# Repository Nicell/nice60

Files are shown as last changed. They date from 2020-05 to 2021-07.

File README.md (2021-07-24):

# This is the old DIY version of the nice!60. This is superseded by a new version, which is fully assembled and much more polished.
# Read more about this new version, and find where to purchase it at https://nicekeyboards.com/nice-60.
## nice60

The nice60 is a hotswap 60% board compatible with Pro Micro footprint boards. This includes the nice!nano, which supports bluetooth.

### BOM
Most parts come from LCSC.

|Qty |Reference(s) |Value |LCSC#/Location |
|----|---|---|---|
|61  |D1-D61 |1N4148 |C108804 |
|8 |D62-D69 |WS2812B |C114586 |
|1 |D70 |SK6812 Mini-E |Buy from Aliexpress|
|1 |J1 |USB C |C165948 |
|1 |J3 |JST-PH (battery) |C173752 |
|61  |MX1-MX61 |Hotswap Sockets |Buy from KBDFans |
|2 |R2, R3 |5.1k |C304897 |
|1 |SW1 |Reset Switch |C388295 |
|1 |U2 |USB ESD Protection |C7519 |
|1 |Stabilizers |4x2u 1x6.25u |Buy from KBDFans |
|6/12|N/A |M2x7mm Standoffs |Buy from Aliexpress|
|1 |USB Cable |Match Pro Micro USB|Anywhere |

### PCB

There are three gerber zips for PCBs.

1. pcb_gerbers.zip - The actual PCB gerbers
2. plate_gerbers.zip - The top plate for the board
3. backplate_gerbers.zip - The bottom case/plate for the board

These can be bought from JLCPCB the cheapest.

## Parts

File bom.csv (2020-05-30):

Item | Qty | Reference(s) | Value | LibPart | Footprint | Datasheet | LCSC
1 | 61 | D1, D2, D3, D4, D5, D6, D7, D8, D9, D10, D11, D12, D13, D14, D15, D16, D17, D18, D19, D20, D21, D22, D23, D24, D25, D26, D27, D28, D29, D30, D31, D32, D33, D34, D35, D36, D37, D38, D39, D40, D41, D42, D43, D44, D45, D46, D47, D48, D49, D50, D51, D52, D53, D54, D55, D56, D57, D58, D59, D60, D61 | D_Small | Device:D_Small | Diode_SMD:D_SOD-123 | ~ | C108804
2 | 8 | D62, D63, D64, D65, D66, D67, D68, D69 | WS2812B | LED:WS2812B | LED_SMD:LED_WS2812B_PLCC4_5.0x5.0mm_P3.2mm | https://cdn-shop.adafruit.com/datasheets/WS2812B.pdf | C114586
3 | 1 | D70 | SK6812 Mini-E | LED:WS2812B | nice60:SK6812Mini-E | https://cdn-shop.adafruit.com/datasheets/WS2812B.pdf | Buy from Aliexpress
5 | 1 | J1 | USB_C_Receptacle_USB2.0 | Connector:USB_C_Receptacle_USB2.0 | Type-C:HRO-TYPE-C-31-M-12-HandSoldering | https://www.usb.org/sites/default/files/documents/usb_type-c.zip | C165948
7 | 1 | J3 | Conn_01x02_Female | Connector:Conn_01x02_Female | Connector_JST:JST_PH_S2B-PH-K_1x02_P2.00mm_Horizontal | ~ | C173752
8 | 61 | MX1, MX2, MX3, MX4, MX5, MX6, MX7, MX8, MX9, MX10, MX11, MX12, MX13, MX14, MX15, MX16, MX17, MX18, MX19, MX20, MX21, MX22, MX23, MX24, MX25, MX26, MX27, MX28, MX29, MX30, MX31, MX32, MX33, MX34, MX35, MX36, MX37, MX38, MX39, MX40, MX41, MX42, MX43, MX44, MX45, MX46, MX47, MX48, MX49, MX50, MX51, MX52, MX53, MX54, MX55, MX56, MX57, MX58, MX59, MX60, MX61 | MX-LED | MX_Alps_Hybrid:MX-NoLED | MX_Only:MXOnly-1U-Hotswap |  | Buy from KBDFans
16 | 2 | R2, R3 | 5.1k | Device:R_Small | Resistor_SMD:R_1206_3216Metric_Pad1.42x1.75mm_HandSolder | ~ | C304897
17 | 1 | SW1 | SW_Push | Switch:SW_Push | Button_Switch_SMD:SW_SPST_TL3342 | ~ | C388295
19 | 1 | U2 | USBLC6-2SC6 | Power_Protection:USBLC6-2SC6 | Package_TO_SOT_SMD:SOT-23-6 | http://www2.st.com/resource/en/datasheet/CD00050750.pdf | C7519

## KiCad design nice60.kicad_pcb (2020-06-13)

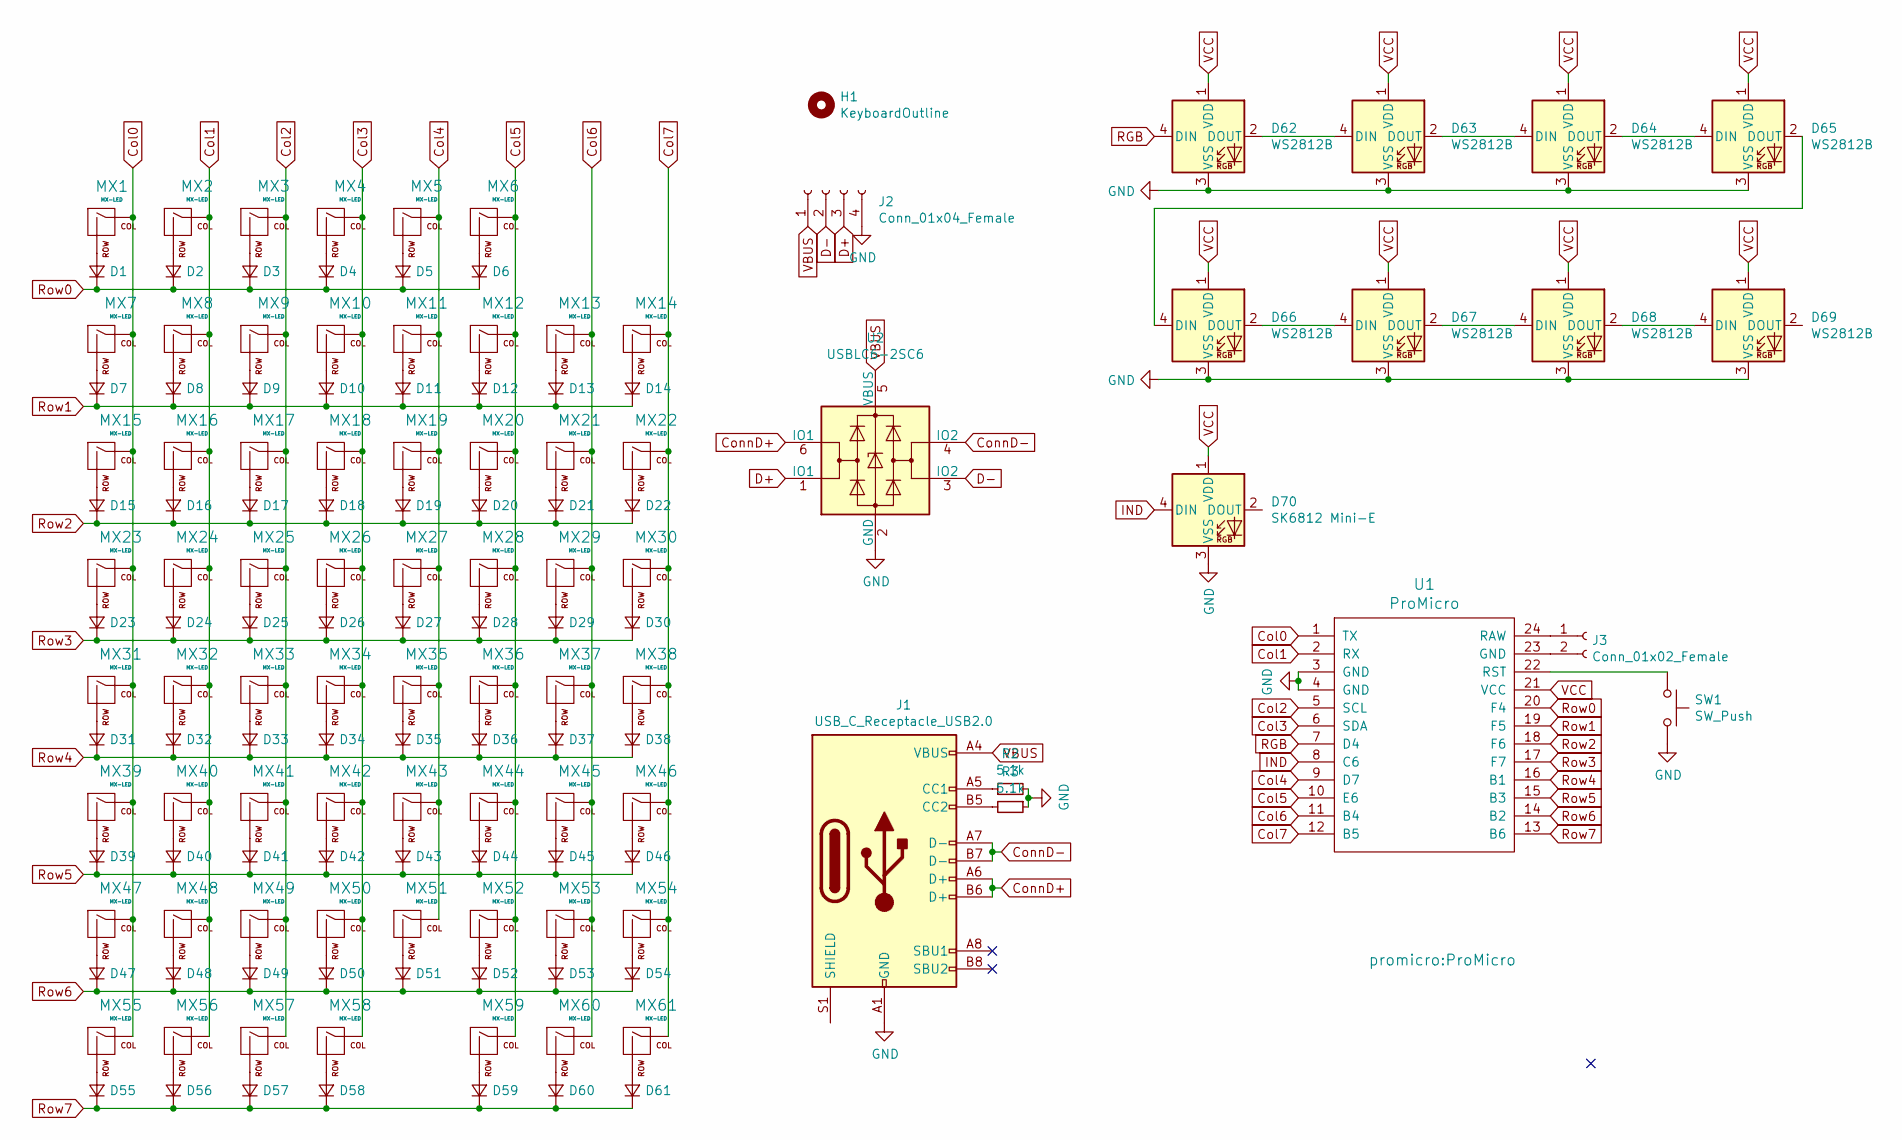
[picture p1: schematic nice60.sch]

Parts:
D1, D2, D3, D4, D5, D6, D7, D8, D9, D10, D11, D12, D13, D14, D15, D16, D17, D18, D19, D20, D21, D22, D23, D24, D25, D26, D27, D28, D29, D30, D31, D32, D33, D34, D35, D36, D37, D38, D39, D40, D41, D42, D43, D44, D45, D46, D47, D48, D49, D50, D51, D52, D53, D54, D55, D56, D57, D58, D59, D60, D61: D_Small; D_SOD-123; LCSC C108804
D62, D63, D64, D65, D66, D67, D68, D69: WS2812B; LED_WS2812B_PLCC4_5.0x5.0mm_P3.2mm; LCSC C114586
D70: SK6812 Mini-E; SK6812Mini-E
H1: KeyboardOutline; 60_Outline-Modded-Type-C
J1: USB_C_Receptacle_USB2.0; HRO-TYPE-C-31-M-12-HandSoldering; LCSC C165948
J2: Conn_01x04_Female; PinSocket_1x04_P2.54mm_Vertical
J3: Conn_01x02_Female; JST_PH_S2B-PH-K_1x02_P2.00mm_Horizontal; LCSC C173752
MX1, MX2, MX3, MX4, MX5, MX6, MX7, MX8, MX9, MX10, MX11, MX12, MX13, MX15, MX16, MX17, MX18, MX19, MX20, MX21, MX22, MX23, MX24, MX25, MX26, MX27, MX28, MX29, MX32, MX33, MX34, MX35, MX36, MX37, MX40, MX41, MX42, MX43, MX44, MX45, MX48, MX49, MX50, MX51, MX52, MX53: MX-LED; MXOnly-1U-Hotswap
MX14: MX-LED; MXOnly-2U-Hotswap
MX30, MX31: MX-LED; MXOnly-1.5U-Hotswap
MX38, MX47: MX-LED; MXOnly-2.25U-Hotswap
MX39: MX-LED; MXOnly-1.75U-Hotswap
MX46: MX-LED; MXOnly-2.75U-Hotswap
MX54, MX55, MX56, MX57, MX59, MX60, MX61: MX-LED; MXOnly-1.25U-Hotswap
MX58: MX-LED; MXOnly-6.25U-Hotswap-ReversedStabilizers
R2, R3: 5.1k; R_1206_3216Metric_Pad1.42x1.75mm_HandSolder; LCSC C304897
SW1: SW_Push; SW_SPST_TL3342; LCSC C388295
U1: ProMicro
U2: USBLC6-2SC6; SOT-23-6; LCSC C7519

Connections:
Col0: MX1.1 (COL), MX7.1 (COL), MX15.1 (COL), MX23.1 (COL), MX31.1 (COL), MX39.1 (COL), MX47.1 (COL), MX55.1 (COL), U1.1 (TX)
Col1: MX2.1 (COL), MX8.1 (COL), MX16.1 (COL), MX24.1 (COL), MX32.1 (COL), MX40.1 (COL), MX48.1 (COL), MX56.1 (COL), U1.2 (RX)
Col2: MX3.1 (COL), MX9.1 (COL), MX17.1 (COL), MX25.1 (COL), MX33.1 (COL), MX41.1 (COL), MX49.1 (COL), MX57.1 (COL), U1.5 (SCL)
Col3: MX4.1 (COL), MX10.1 (COL), MX18.1 (COL), MX26.1 (COL), MX34.1 (COL), MX42.1 (COL), MX50.1 (COL), MX58.1 (COL), U1.6 (SDA)
Col4: MX5.1 (COL), MX11.1 (COL), MX19.1 (COL), MX27.1 (COL), MX35.1 (COL), MX43.1 (COL), MX51.1 (COL), U1.9 (D7)
Col5: MX6.1 (COL), MX12.1 (COL), MX20.1 (COL), MX28.1 (COL), MX36.1 (COL), MX44.1 (COL), MX52.1 (COL), MX59.1 (COL), U1.10 (E6)
Col6: MX13.1 (COL), MX21.1 (COL), MX29.1 (COL), MX37.1 (COL), MX45.1 (COL), MX53.1 (COL), MX60.1 (COL), U1.11 (B4)
Col7: MX14.1 (COL), MX22.1 (COL), MX30.1 (COL), MX38.1 (COL), MX46.1 (COL), MX54.1 (COL), MX61.1 (COL), U1.12 (B5)
ConnD+: J1.A6 (D+), J1.B6 (D+), U2.6 (IO1)
ConnD-: J1.A7 (D-), J1.B7 (D-), U2.4 (IO2)
D+: J2.3, U2.1 (IO1)
D-: J2.2, U2.3 (IO2)
GND: D62.3 (VSS), D63.3 (VSS), D64.3 (VSS), D65.3 (VSS), D66.3 (VSS), D67.3 (VSS), D68.3 (VSS), D69.3 (VSS), D70.3 (VSS), J1.A1 (GND), J1.A12 (GND), J1.B1 (GND), J1.B12 (GND), J2.4, R2.2, R3.1, SW1.2, U1.3 (GND), U1.4 (GND), U2.2 (GND)
IND: D70.4 (DIN), U1.8 (C6)
unnamed: D1.2 (A), MX1.2 (ROW)
unnamed: D2.2 (A), MX2.2 (ROW)
unnamed: D3.2 (A), MX3.2 (ROW)
unnamed: D4.2 (A), MX4.2 (ROW)
unnamed: D5.2 (A), MX5.2 (ROW)
unnamed: D6.2 (A), MX6.2 (ROW)
unnamed: D7.2 (A), MX7.2 (ROW)
unnamed: D8.2 (A), MX8.2 (ROW)
unnamed: D9.2 (A), MX9.2 (ROW)
unnamed: D10.2 (A), MX10.2 (ROW)
unnamed: D11.2 (A), MX11.2 (ROW)
unnamed: D12.2 (A), MX12.2 (ROW)
unnamed: D13.2 (A), MX13.2 (ROW)
unnamed: D14.2 (A), MX14.2 (ROW)
unnamed: D15.2 (A), MX15.2 (ROW)
unnamed: D16.2 (A), MX16.2 (ROW)
unnamed: D17.2 (A), MX17.2 (ROW)
unnamed: D18.2 (A), MX18.2 (ROW)
unnamed: D19.2 (A), MX19.2 (ROW)
unnamed: D20.2 (A), MX20.2 (ROW)
unnamed: D21.2 (A), MX21.2 (ROW)
unnamed: D22.2 (A), MX22.2 (ROW)
unnamed: D23.2 (A), MX23.2 (ROW)
unnamed: D24.2 (A), MX24.2 (ROW)
unnamed: D25.2 (A), MX25.2 (ROW)
unnamed: D26.2 (A), MX26.2 (ROW)
unnamed: D27.2 (A), MX27.2 (ROW)
unnamed: D28.2 (A), MX28.2 (ROW)
unnamed: D29.2 (A), MX29.2 (ROW)
unnamed: D30.2 (A), MX30.2 (ROW)
unnamed: D31.2 (A), MX31.2 (ROW)
unnamed: D32.2 (A), MX32.2 (ROW)
unnamed: D33.2 (A), MX33.2 (ROW)
unnamed: D34.2 (A), MX34.2 (ROW)
unnamed: D35.2 (A), MX35.2 (ROW)
unnamed: D36.2 (A), MX36.2 (ROW)
unnamed: D37.2 (A), MX37.2 (ROW)
unnamed: D38.2 (A), MX38.2 (ROW)
unnamed: D39.2 (A), MX39.2 (ROW)
unnamed: D40.2 (A), MX40.2 (ROW)
unnamed: D41.2 (A), MX41.2 (ROW)
unnamed: D42.2 (A), MX42.2 (ROW)
unnamed: D43.2 (A), MX43.2 (ROW)
unnamed: D44.2 (A), MX44.2 (ROW)
unnamed: D45.2 (A), MX45.2 (ROW)
unnamed: D46.2 (A), MX46.2 (ROW)
unnamed: D47.2 (A), MX47.2 (ROW)
unnamed: D48.2 (A), MX48.2 (ROW)
unnamed: D49.2 (A), MX49.2 (ROW)
unnamed: D50.2 (A), MX50.2 (ROW)
unnamed: D51.2 (A), MX51.2 (ROW)
unnamed: D52.2 (A), MX52.2 (ROW)
unnamed: D53.2 (A), MX53.2 (ROW)
unnamed: D54.2 (A), MX54.2 (ROW)
unnamed: D55.2 (A), MX55.2 (ROW)
unnamed: D56.2 (A), MX56.2 (ROW)
unnamed: D57.2 (A), MX57.2 (ROW)
unnamed: D58.2 (A), MX58.2 (ROW)
unnamed: D59.2 (A), MX59.2 (ROW)
unnamed: D60.2 (A), MX60.2 (ROW)
unnamed: D61.2 (A), MX61.2 (ROW)
unnamed: D62.2 (DOUT), D63.4 (DIN)
unnamed: D63.2 (DOUT), D64.4 (DIN)
unnamed: D64.2 (DOUT), D65.4 (DIN)
unnamed: D65.2 (DOUT), D66.4 (DIN)
unnamed: D66.2 (DOUT), D67.4 (DIN)
unnamed: D67.2 (DOUT), D68.4 (DIN)
unnamed: D68.2 (DOUT), D69.4 (DIN)
unnamed: J1.A5 (CC1), R2.1
unnamed: J1.B5 (CC2), R3.2
unnamed 88: J3.1, U1.24 (RAW); also elsewhere on the board
unnamed 89: J3.2, U1.23 (GND); also elsewhere on the board
unnamed: SW1.1, U1.22 (RST)
RGB: D62.4 (DIN), U1.7 (D4)
Row0: D1.1 (K), D2.1 (K), D3.1 (K), D4.1 (K), D5.1 (K), D6.1 (K), U1.20 (F4)
Row1: D7.1 (K), D8.1 (K), D9.1 (K), D10.1 (K), D11.1 (K), D12.1 (K), D13.1 (K), D14.1 (K), U1.19 (F5)
Row2: D15.1 (K), D16.1 (K), D17.1 (K), D18.1 (K), D19.1 (K), D20.1 (K), D21.1 (K), D22.1 (K), U1.18 (F6)
Row3: D23.1 (K), D24.1 (K), D25.1 (K), D26.1 (K), D27.1 (K), D28.1 (K), D29.1 (K), D30.1 (K), U1.17 (F7)
Row4: D31.1 (K), D32.1 (K), D33.1 (K), D34.1 (K), D35.1 (K), D36.1 (K), D37.1 (K), D38.1 (K), U1.16 (B1)
Row5: D39.1 (K), D40.1 (K), D41.1 (K), D42.1 (K), D43.1 (K), D44.1 (K), D45.1 (K), D46.1 (K), U1.15 (B3)
Row6: D47.1 (K), D48.1 (K), D49.1 (K), D50.1 (K), D51.1 (K), D52.1 (K), D53.1 (K), D54.1 (K), U1.14 (B2)
Row7: D55.1 (K), D56.1 (K), D57.1 (K), D58.1 (K), D59.1 (K), D60.1 (K), D61.1 (K), U1.13 (B6)
VBUS: J1.A4 (VBUS), J1.A9 (VBUS), J1.B4 (VBUS), J1.B9 (VBUS), J2.1, U2.5 (VBUS)
VCC: D62.1 (VDD), D63.1 (VDD), D64.1 (VDD), D65.1 (VDD), D66.1 (VDD), D67.1 (VDD), D68.1 (VDD), D69.1 (VDD), D70.1 (VDD), U1.21 (VCC)

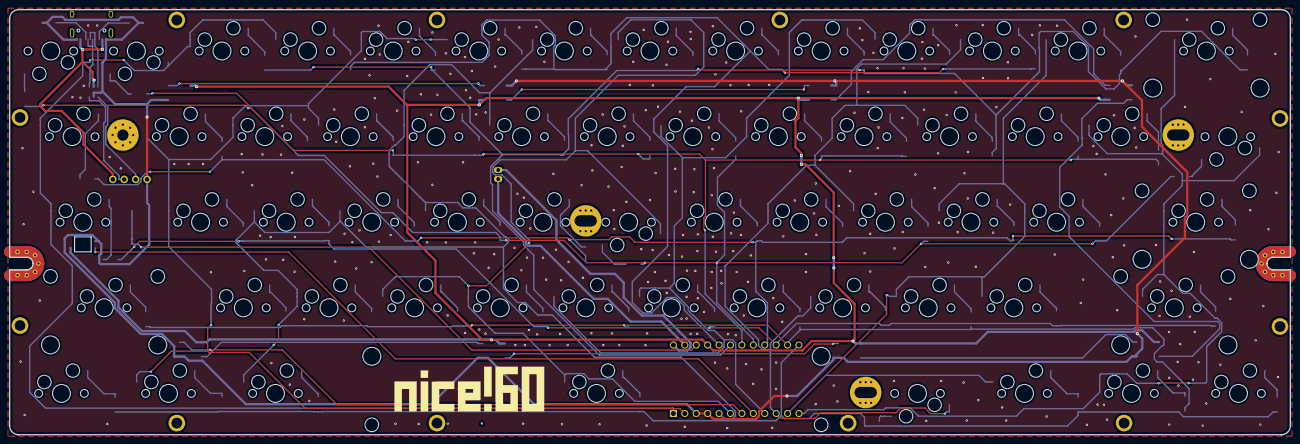
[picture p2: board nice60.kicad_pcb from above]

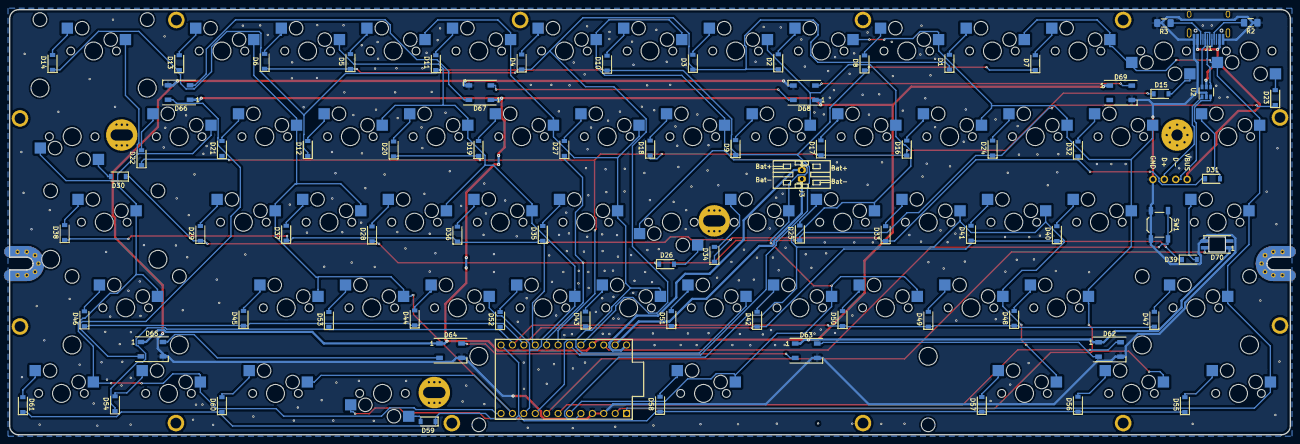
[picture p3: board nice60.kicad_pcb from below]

Board: 2 copper layers, 285.0 x 94.6 mm, 141 parts (77 on the bottom side), 98 nets.

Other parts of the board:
J3#2: Conn_01x02_Female; JST_PH_S2B-PH-K_1x02_P2.00mm_Horizontal

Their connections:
unnamed 88: J3#2.1; also elsewhere on the board
unnamed 89: J3#2.2; also elsewhere on the board

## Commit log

2020-06-01 Fix plate to have solder mask and 3mm thick edges
    [plate.kicad_pcb]
2020-06-08 Fix VBUS connection to ESD protection
    [nice60.kicad_pcb, nice60.sch]
2020-06-13 Add better JST connector silkscreen
    [nice60.kicad_pcb]
